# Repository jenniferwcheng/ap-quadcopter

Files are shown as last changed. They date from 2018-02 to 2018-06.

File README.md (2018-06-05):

# IEEE@UCLA Advanced 2017-2018
Quadcopter

## Process:
* Select Pro Mini in Aruduino IDE
* Compile + Upload
* If it doesn't work, try pressing/holding the reset button on the board between compile and upload

## Layout of Motors:
```
RB = Red/Blue
BW = Black/White
RB BW
BW RB
```

## TO-DO:
* Figure out ports and #define them all
* Crimp motor wires and attach them via female JST to board
* Get battery and test individual motor (analogWrite to control speed)
* Attach all motors to plastic body
* Try flying while held down with all 4 motors and rotors
* Attach gyroscope/accelerometer
* Do actual error correction + control using sensors
* Attach radio
* Implement radio control

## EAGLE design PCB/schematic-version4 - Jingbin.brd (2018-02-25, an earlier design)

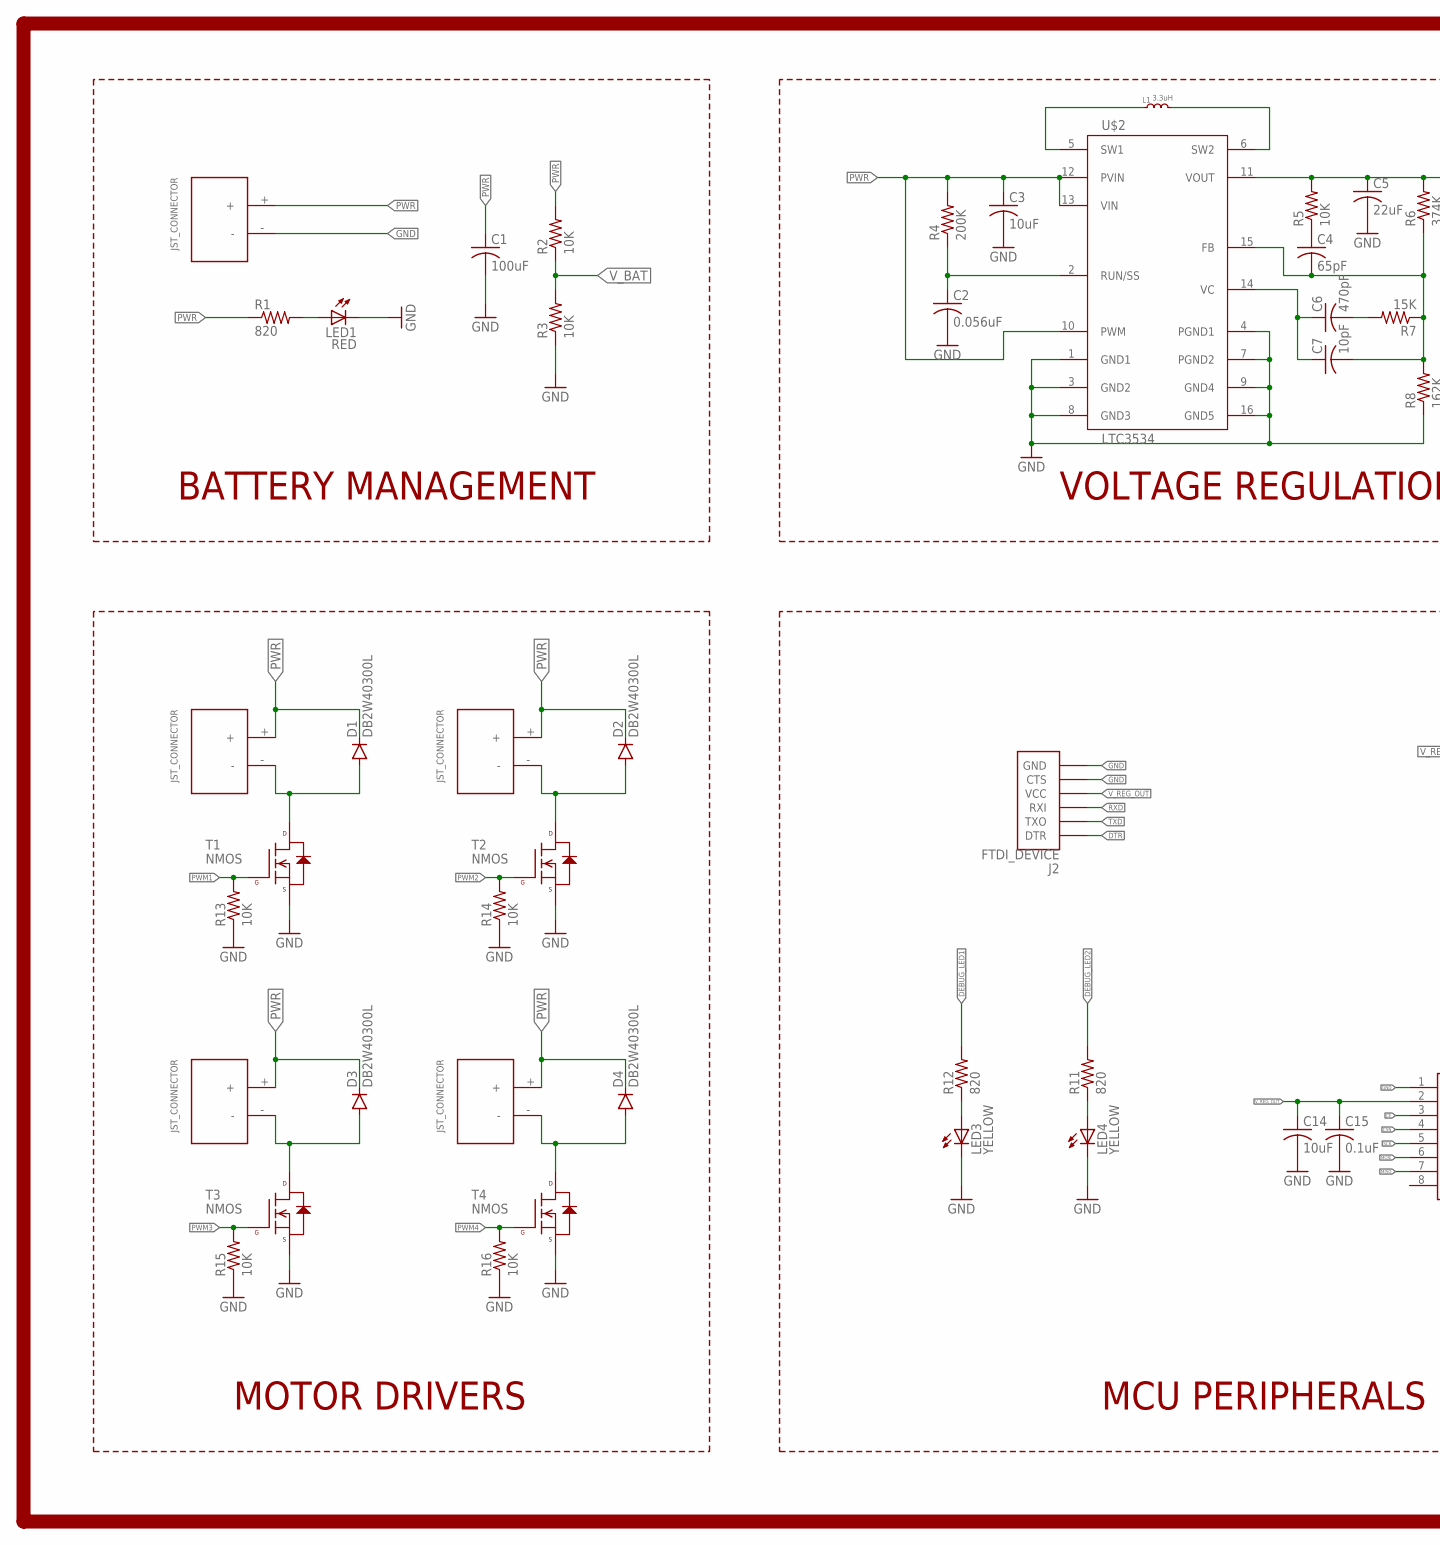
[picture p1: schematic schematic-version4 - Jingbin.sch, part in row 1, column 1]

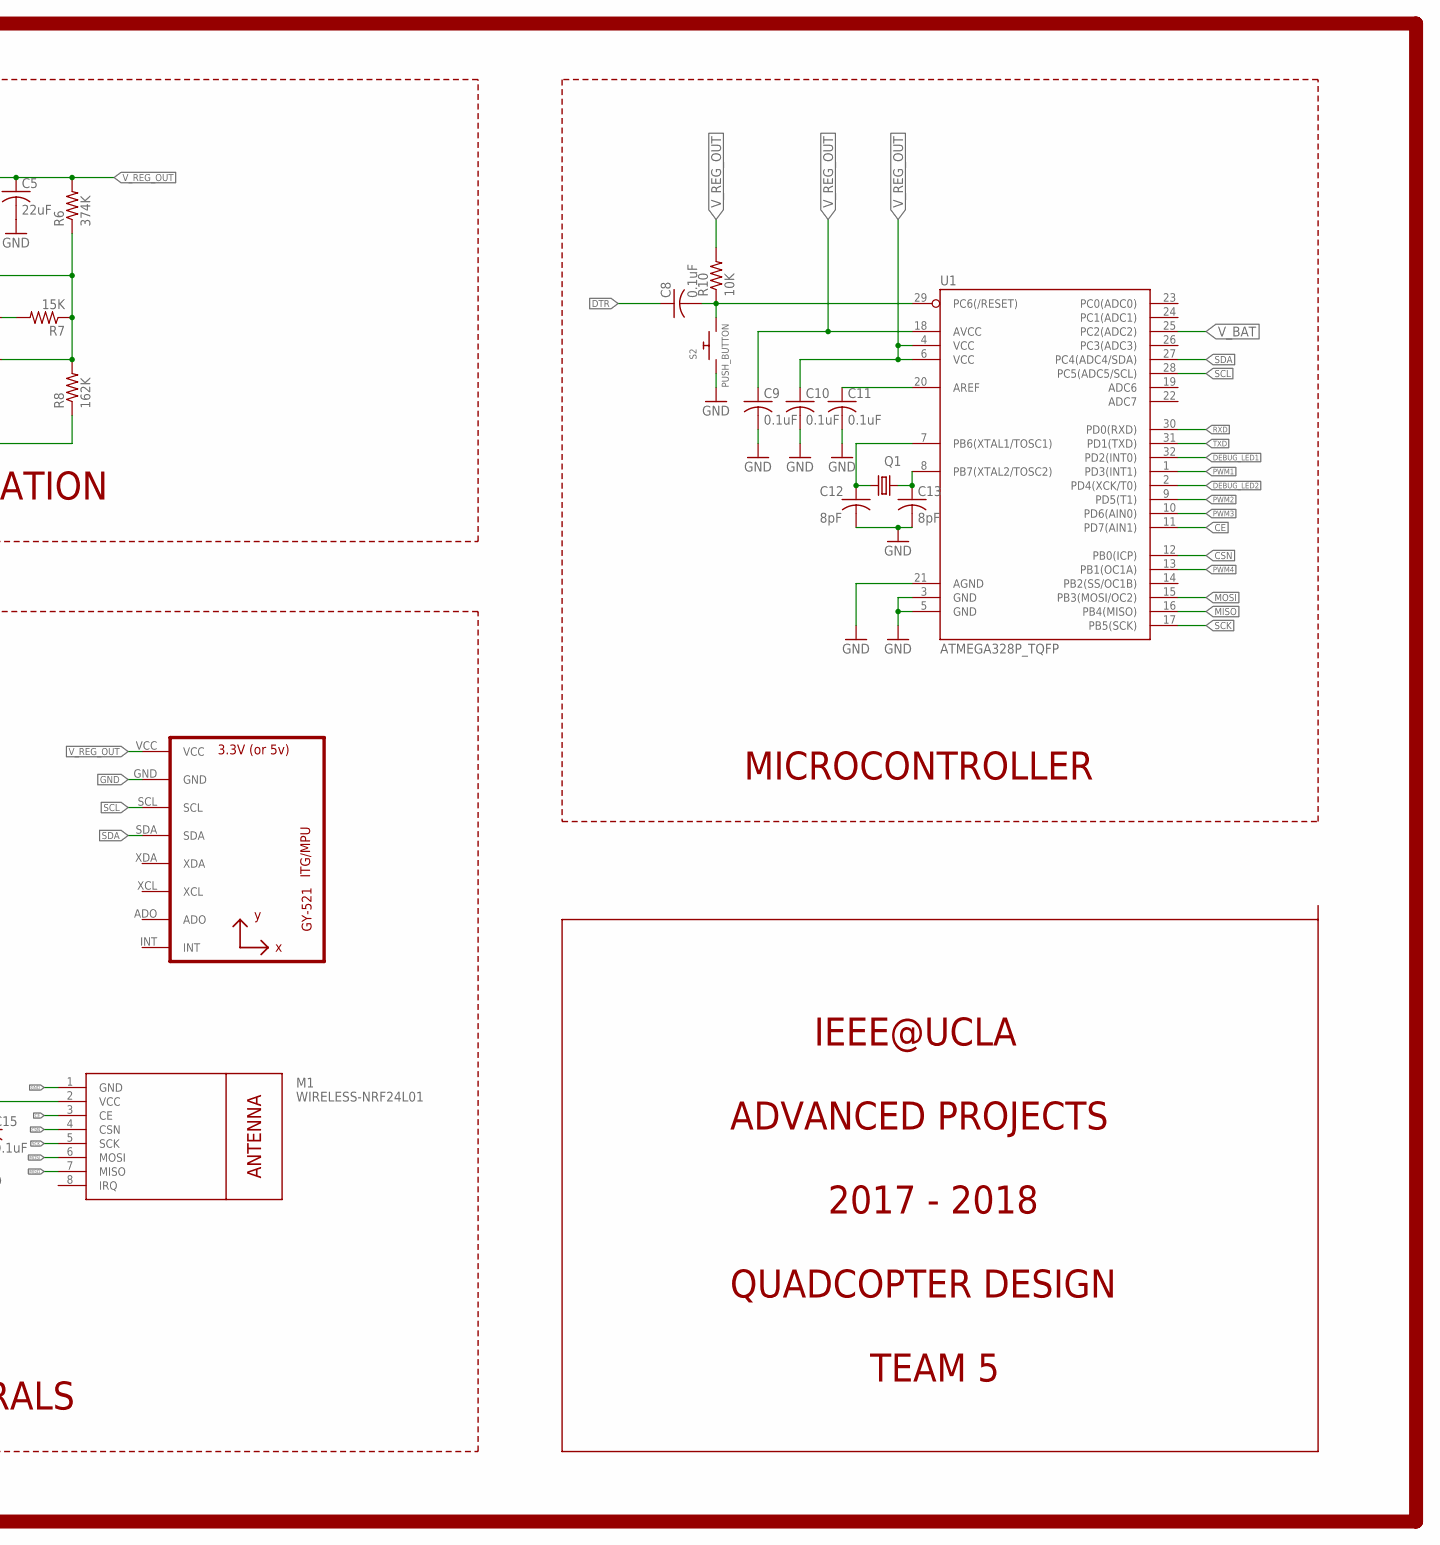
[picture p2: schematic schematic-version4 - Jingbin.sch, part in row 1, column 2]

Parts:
C1: 100uF; C1206
C2: 0.056uF; C0603
C3, C14: 10uF; C0603
C4: 65pF; C1206
C5: 22uF; C0603
C6: 470pF; C0603
C7: 10pF; C0603
C8, C9, C10, C11, C15: 0.1uF; C0603
C12, C13: 8pF; C0603
D1, D2, D3, D4: DB2W40300L; MINI2-F3-B
J2: FTDI_DEVICE; FTDI_DEVICE_SIDE
L1: 3.3uH; XAL4020
LED1: RED; SML0603
LED3, LED4: YELLOW; SML0603
M1: WIRELESS-NRF24L01
Q1: NX3225GD; NX3225GD-CRA-3
R1, R11, R12: 820; R0603
R2, R3, R5, R10, R13, R14, R15, R16: 10K; R0603
R4: 200K; R0603
R6: 374K; R0603
R7: 15K; R0603
R8: 162K; R0603
S2: PUSH_BUTTON; PUSHBUTTON_SMD_SJ
T1, T2, T3, T4: NMOS; SOT23-3
U1: ATMEGA328P_TQFP; TQFP32-08
U2: GY-521MPU6050; GY-521
U$1, U$4, U$7, U$10, U$13: JST_CONNECTOR_FEMALE
U$2: LTC3534; SSOP-16GN

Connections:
CE: M1.3 (CE), U1.11 (PD7(AIN1))
CSN: M1.4 (CSN), U1.12 (PB0(ICP))
DEBUG_LED1: R12.2, U1.32 (PD2(INT0))
DEBUG_LED2: R11.2, U1.2 (PD4(XCK/T0))
DTR: C8.1, J2.P$1 (DTR)
GND: C1.2, C2.2, C3.2, C5.2, C9.2, C10.2, C11.2, C12.2, C13.2, C14.2, C15.2, J2.P$5 (CTS), J2.P$6 (GND), LED1.C, LED3.C, LED4.C, M1.1 (GND), R3.1, R8.1, R13.1, R14.1, R15.1, R16.1, S2.P$1, T1.2 (S), T2.2 (S), T3.2 (S), T4.2 (S), U1.3 (GND), U1.5 (GND), U1.21 (AGND), U2.GND, U$1.-, U$2.1 (GND1), U$2.3 (GND2), U$2.4 (PGND1), U$2.7 (PGND2), U$2.8 (GND3), U$2.9 (GND4), U$2.16 (GND5)
MISO: M1.7 (MISO), U1.16 (PB4(MISO))
MOSI: M1.6 (MOSI), U1.15 (PB3(MOSI/OC2))
unnamed: C12.1, Q1.P$1 (1), U1.7 (PB6(XTAL1/TOSC1))
unnamed: C8.2, R10.1, S2.P$2, U1.29 (PC6(/RESET))
unnamed: D1.POS (PPIN), T1.3 (D), U$4.-
unnamed: C13.1, Q1.P$2 (2), U1.8 (PB7(XTAL2/TOSC2))
unnamed: D2.POS (PPIN), T2.3 (D), U$7.-
unnamed: D3.POS (PPIN), T3.3 (D), U$10.-
unnamed: D4.POS (PPIN), T4.3 (D), U$13.-
unnamed: L1.1, U$2.5 (SW1)
unnamed: L1.2, U$2.6 (SW2)
unnamed: LED1.A, R1.2
unnamed: LED3.A, R12.1
unnamed: LED4.A, R11.1
unnamed: C4.1, R5.1
unnamed: C2.1, R4.1, U$2.2 (RUN/SS)
unnamed: C4.2, C7.2, R6.1, R7.1, R8.2, U$2.15 (FB)
unnamed: C6.1, C7.1, U$2.14 (VC)
unnamed: C6.2, R7.2
unnamed: C11.1, U1.20 (AREF)
PWM1: R13.2, T1.1 (G), U1.1 (PD3(INT1))
PWM2: R14.2, T2.1 (G), U1.9 (PD5(T1))
PWM3: R15.2, T3.1 (G), U1.10 (PD6(AIN0))
PWM4: R16.2, T4.1 (G), U1.13 (PB1(OC1A))
PWR: C1.1, C3.1, D1.NEG (GPIN), D2.NEG (GPIN), D3.NEG (GPIN), D4.NEG (GPIN), R1.1, R2.2, R4.2, U$1.+, U$2.10 (PWM), U$2.12 (PVIN), U$2.13 (VIN), U$4.+, U$7.+, U$10.+, U$13.+
RXD: J2.P$3 (RXI), U1.30 (PD0(RXD))
SCK: M1.5 (SCK), U1.17 (PB5(SCK))
SCL: U1.28 (PC5(ADC5/SCL)), U2.SCL
SDA: U1.27 (PC4(ADC4/SDA)), U2.SDA
TXD: J2.P$2 (TXO), U1.31 (PD1(TXD))
V_BAT: R2.1, R3.2, U1.25 (PC2(ADC2))
V_REG_OUT: C5.1, C9.1, C10.1, C14.1, C15.1, J2.P$4 (VCC), M1.2 (VCC), R5.2, R6.2, R10.2, U1.4 (VCC), U1.6 (VCC), U1.18 (AVCC), U2.VCC, U$2.11 (VOUT)

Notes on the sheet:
BATTERY MANAGEMENT
VOLTAGE REGULATION
MOTOR DRIVERS
MCU PERIPHERALS
MICROCONTROLLER
IEEE@UCLA
ADVANCED PROJECTS
2017 - 2018
QUADCOPTER DESIGN
TEAM 5

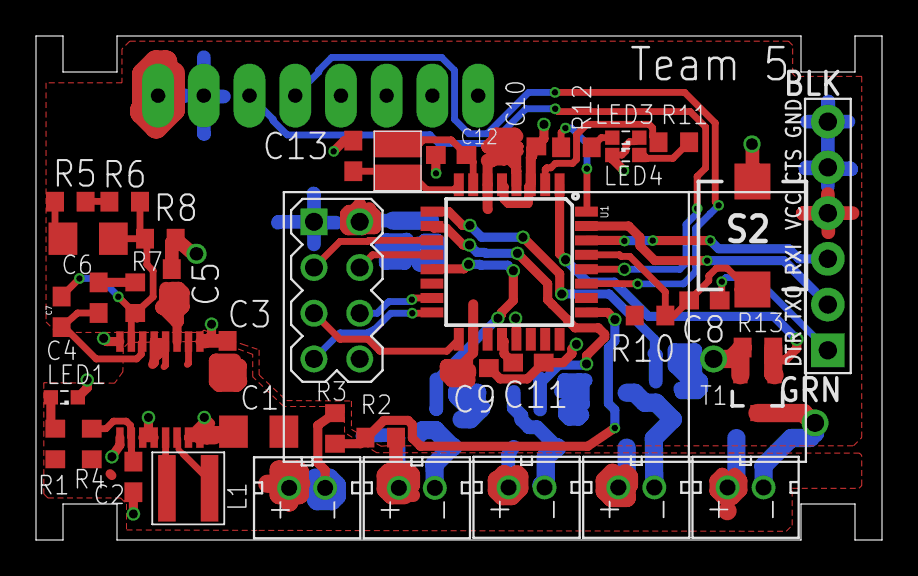
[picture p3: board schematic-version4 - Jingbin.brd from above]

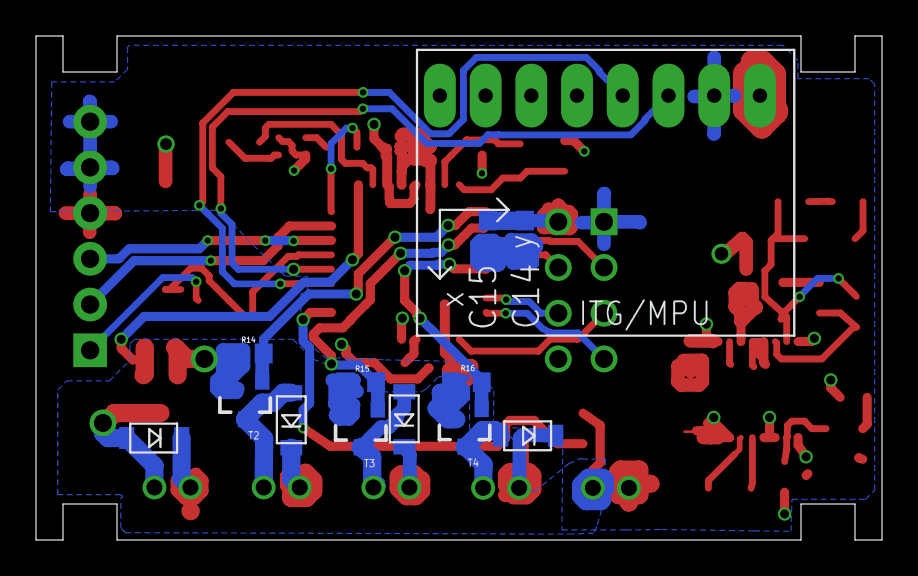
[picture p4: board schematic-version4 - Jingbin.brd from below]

Board: 2 copper layers, 47.0 x 28.0 mm, 54 parts (13 on the bottom side), 38 nets.

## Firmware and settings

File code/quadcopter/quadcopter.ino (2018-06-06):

#define PWM1 3
#define PWM2 5
#define PWM3 6
#define PWM4 9

#define debug1 2
#define debug2 4

#define SCL A5
#define SDA A4

#define CE 7
#define CSN 8
#define MOSI 11
#define MISO 12

void setup() {
  //setup_gyro();
  pinMode(PWM1,OUTPUT);
  pinMode(PWM2,OUTPUT);
  pinMode(PWM3,OUTPUT);
  pinMode(PWM4,OUTPUT);
  pinMode(debug1,OUTPUT);
  pinMode(debug2,OUTPUT);
}

void loop() {
  //loop_gyro();
  digitalWrite(debug1,HIGH);
  digitalWrite(debug2,HIGH);

  analogWrite(PWM4,10);
  analogWrite(PWM3,10);
  analogWrite(PWM2,10);
  analogWrite(PWM1,10);
  delay(1000);

  digitalWrite(debug1,LOW);
  digitalWrite(debug2,LOW);

  delay(100);
}

// sensor fusion stuff
#include "sensor_fusion.h"
// DEFINE INT_STATUS IN HEADER

struct vector bias_a, bias_g, orient, orient_c;
int max_Samples = 75;
unsigned long timel = 0;
unsigned long prev_time = 0;

struct data{
  int x,y,z;
} acc, gyro;

void setup_gyro() {
  //configure device
  //set PWR_MGMT_1 register to take the IMU out of sleep mode
  uint8_t pwr_mgmt_1;
  readReg(0x6B, &pwr_mgmt_1, 1);
  pwr_mgmt_1 = 0xBF & pwr_mgmt_1; //disable SLEEP
  writeReg(0x6B, &pwr_mgmt_1, 1);
  //set GYRO_CONFIG register to the largest possible full-scale range to enable the
  //detection of high-velocity rotations
  uint8_t gyro_config;
  readReg(0x1B, &gyro_config, 1);
  gyro_config = 0x18 | gyro_config; //highest thingy
  writeReg(0x1B, &gyro_config, 1);
  //set CONFIG register to the largest possible bandwidth
  uint8_t configy;
  readReg(0x1A, &configy, 1);
  configy = 0xF8 & configy;
  writeReg(0x1A, &configy, 1);
  //enable DATA_RDY
//  uint8_t RDY;
//  readReg(0x38, &RDY, 1);
//  RDY = RDY | 0x01;
//  writeReg(0x38, &RDY, 1);

  Serial.begin(115200);
  //uint8_t *WHOAMI;
  //readReg(0x75,WHOAMI,1);
  //Serial.println(String(*WHOAMI));

  bias_a.x = bias_a.y = bias_a.z = 0;
  bias_g.x = bias_g.y = bias_g.z = 0;

  // Get samples
  for (int i = 1; i <= max_Samples; i++) {

    if (getData()) {

      bias_a.x += ((float)acc.x)/16384 - 0;
      bias_a.y += ((float)acc.y)/16384 - 0;
      bias_a.z += ((float)acc.z)/16384 - 1;

      bias_g.x += ((float)gyro.x)/16.384 - 0;
      bias_g.y += ((float)gyro.y)/16.384 - 0;
      bias_g.z += ((float)gyro.z)/16.384 - 0;

      //Serial.println("Loop" + String(i));
      //printVector(bias_a);
      //printVector(bias_g);
      //printVector(acc,"acc");
      //printVector(gyro,"gyro");
    }
    else {
      //Serial.println("No data");
      i--;
    }
  }

  bias_a.x /= max_Samples;
  bias_a.y /= max_Samples;
  bias_a.z /= max_Samples;

  bias_g.x /= max_Samples;
  bias_g.y /= max_Samples;
  bias_g.z /= max_Samples;

//  printVector(bias_a);
//  printVector(bias_g);
  //init orient to up
  orient.x = orient.y = 0;
  orient.z = 1;

  orient_c.x = orient_c.y = 0;
  orient_c.z = 1;
}



void loop_gyro() {
  if (getData()) {
    //find unit acceleration vector
    struct vector a=scaleReading(acc,"acc");
    vector unit_a;
    vector_normalize(&a, &unit_a);
    printVector(unit_a);

    //rotate quaternion to show orientation
    struct vector g = scaleReading(gyro,"gyro");
    vector unit_g;
    float len = vector_normalize(&g, &unit_g);
    struct quaternion q;
    timel = micros();
    //Serial.print(" ");
    //Serial.println(len,4);

    //deal with init case
    if(prev_time == 0) len = 0;

    float timebt = (timel-prev_time)/1000000.0;
//    Serial.println(timebt,4);
    quaternion_create(&unit_g, -len*timebt, &q);
    prev_time = timel;

    vector result;
    quaternion_rotate(&orient, &q, &result);
    orient = result;
    Serial.print(" ");
    printVector(orient);

    //complementary filter

    //apply low/high pass filter

    //add and normalize
    vector comp,sum,p1,p2,r;
    
    quaternion_rotate(&orient_c, &q, &r);
    float alpha = 0.5;
    vector_multiply(&unit_a, alpha, &p1);
    vector_multiply(&r, 1.0-alpha, &p2);
    vector_add(&p1, &p2, &sum);
    vector_normalize(&sum, &comp);

    Serial.print(" ");
    printVector(comp);
    Serial.println();

    orient_c = comp;
  }

  
  delay(10);
}

void printVector(struct vector v) {
  Serial.print(v.x);
  Serial.print(" ");
  Serial.print(v.y);
  Serial.print(" ");
  Serial.print(v.z);
  //Serial.println();
}

struct vector scaleReading(struct data a, String s){
  struct vector v;
  if(s=="acc"){
    v.x=((float)a.x)/16384-bias_a.x;
    v.y=((float)a.y)/16384-bias_a.y;
    v.z=((float)a.z)/16384-bias_a.z;
  }
  else {
    v.x=((float)a.x)/16.384-bias_g.x;
    v.y=((float)a.y)/16.384-bias_g.y;
    v.z=((float)a.z)/16.384-bias_g.z;
    v.x *= 0.017453;
    v.y *= 0.017453;
    v.z *= 0.017453;
  }
  return v;
}

//convert to g's and print
void printVector(struct data v, String s) {
  if (s=="acc"){
    Serial.print((((float)v.x)/16384),4);
    Serial.print(" ");
    Serial.print((((float)v.y)/16384),4);
    Serial.print(" ");
    Serial.print((((float)v.z)/16384),4);
    Serial.println();
  }
  else {
    Serial.print((((float)v.x)/16.4),4);
    Serial.print(" ");
    Serial.print((((float)v.y)/16.4),4);
    Serial.print(" ");
    Serial.print((((float)v.z)/16.4),4);
    Serial.println();
  }
}

/* Get data about x y z coordinates from accelerometer and gyroscope.
   Takes in two structs, acc and gyro. If data is available, acc and gyro
   will be filled with the x y z coordinates and the function returns true.
   Otherwise it returns false and structs are not touched.*/
bool getData() {
  uint8_t buf,buf2;
  readReg(0x3A, &buf, 1);
  //Serial.println(String(buf));
  if ((buf)&0x01) {
    //read acc
    readReg(0x3B, &buf, 1);
    readReg(0x3C, &buf2, 1);
    acc.x = (buf<<8) | buf2;
    readReg(0x3D, &buf, 1);
    readReg(0x3E, &buf2, 1);
    acc.y = (buf<<8) | buf2;
    readReg(0x3F, &buf, 1);
    readReg(0x40, &buf2, 1);
    acc.z = (buf<<8) | buf2;

    //read gyro
    readReg(0x43, &buf, 1);
    readReg(0x44, &buf2, 1);
    gyro.x = (buf<<8) | buf2;
    readReg(0x45, &buf, 1);
    readReg(0x46, &buf2, 1);
    gyro.y = (buf<<8) | buf2;
    readReg(0x47, &buf, 1);
    readReg(0x48, &buf2, 1);
    gyro.z = (buf<<8) | buf2;

    return true;
  }
  return false;
}

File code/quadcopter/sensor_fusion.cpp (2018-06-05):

#include <Arduino.h>
#include <Wire.h>
#include "sensor_fusion.h"

void readReg(uint8_t reg, uint8_t *buf, size_t len)
{
    // TODO: Implement
	//page 36
	Wire.beginTransmission(0x68); //start condition?
	Wire.write(reg); 
	Wire.endTransmission(false); 
	
	//restarts
	//Wire.endTransmission(false);
	Wire.requestFrom(0x68,len); //request the reg
	for (int i = 0; i < len; i++) {
		//while(!Wire.available()){}
		buf[i] = Wire.read();
	}
	Wire.endTransmission();
	
}

void writeReg(uint8_t reg, uint8_t *buf, size_t len)
{
    // TODO: Implement
	//page 35
	
	Wire.beginTransmission(byte(0x68)); // send AD+W = 0x68 + W bit (0)
	Wire.write(reg); // send RA
	Wire.write(buf,len); // send DATA
	Wire.endTransmission(true); //send stop signal
}

float vector_normalize(struct vector *raw, struct vector *unit)
{
  float mag = sqrt(pow(raw->x, 2) + pow(raw->y, 2) + pow(raw->z, 2));
  if(mag != 0) {
      unit->x = raw->x / mag;
      unit->y = raw->y / mag;
      unit->z = raw->z / mag;
  }
  return mag;
}

void vector_add(struct vector *v1, struct vector *v2, struct vector *result)
{
  result->x = v1->x + v2->x;
  result->y = v1->y + v2->y;
  result->z = v1->z + v2->z;
}

void vector_multiply(struct vector *v, float c, struct vector *result)
{
  result->x = v->x * c;
  result->y = v->y * c;
  result->z = v->z * c;
}

void quaternion_create(struct vector *v, float angle, struct quaternion *result)
{
  result->r = cos(angle/2);
  result->i = v->x * sin(angle/2);
  result->j = v->y * sin(angle/2);
  result->k = v->z * sin(angle/2);
}

void quaternion_rotate(struct vector *v, struct quaternion *q, struct vector *result)
{
  struct vector n;
  memcpy(&n, v, sizeof(n));
  result->x = n.x * (1 - 2*(pow(q->j, 2) + pow(q->k, 2))) + n.y * 2*(q->i * q->j - q->k * q->r) + n.z * 2*(q->i * q->k + q->j * q->r);
  result->y = n.x * 2*(q->i * q->j + q->k * q->r) + n.y * (1 - 2*(pow(q->i, 2) + pow(q->k, 2))) + n.z * 2*(q->j * q->k - q->i * q->r);
  result->z = n.x * 2*(q->i * q->k - q->j * q->r) + n.y * 2*(q->j * q->k + q->i * q->r) + n.z * (1 - 2*(pow(q->i, 2) + pow(q->j, 2)));
}

void quaternion_multiply(struct quaternion *q1, struct quaternion *q2, struct quaternion *result)
{
  result->r = q1->r * q2->r - q1->i * q2->i - q1->j * q2->j - q1->k * q2->k;
  result->i = q1->r * q2->i + q1->i * q2->r + q1->j * q2->k - q1->k * q2->j;
  result->j = q1->r * q2->j - q1->i * q2->k + q1->j * q2->r + q1->k * q2->i;
  result->k = q1->r * q2->k + q1->i * q2->j - q1->j * q2->i + q1->k * q2->r;
}

float vector_roll(struct vector *v)
{
  return atan2(v->x, sqrt(pow(v->z, 2) + pow(v->y, 2)));
}

float vector_pitch(struct vector *v)
{
  return -atan2(v->y, v->z);
}

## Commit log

2018-01-24 Added sensor, RF
    Need work on voltage regulator, header for FDTI, more decoupling,
    [schematic.sch]
2018-01-25 Added (mostly compelte) v-reg circuit
    [schematic.sch]
2018-01-25 completed v_reg external, decouplng, labels
    Need work on adding control switches, indicator LEDs. Need to find all correct parts and replace current placeholder symbols
    [schematic.sch]
2018-01-26 Added LEDs, switches, motor circuit, and made it look pretty
    Still need to get all the correct parts to replace place-holder
    [schematic.sch]
2018-01-26 added pull-down for motor
    [schematic.sch]
2018-01-26 Fixed all warnings, added more debug LEDs
    [schematic.sch]
2018-01-27 Added load capacitor for crystal
    [schematic.sch]
2018-01-28 Updated parts to reflect actual selection
    [schematic.brd, schematic.sch]
2018-01-28 Changed voltage divider values
    [schematic.brd, schematic.sch]
2018-01-28 added slide switch
    [schematic.brd, schematic.sch]
2018-01-28 Included libraries for some parts
    Adafruit for push button.
    Coilcraft for inductor used in voltage regulator.
    Wurth for sliding switch
2018-01-30 Removed switch, changed some names, removed an unnecessary capacitor
    Changed power from battery to PWR instead of VCC, to be exact
    [schematic.brd]
2018-01-31 Fixed issues mentioned in design review
    Changed voltage divider resistors to 10K.
    Got new voltage regulator, completely circuit and PCD footprint.
    Changed all component package to 0603.
    [schematic.brd, schematic.sch]
2018-02-01 Fixed issues from schematic pre-check
    Changed package of R15,R16 to 0603.
    CHange 100pF capacitor to 68pF to be closer to recommended value.
    [schematic.brd, schematic.sch]
2018-02-02 65pF capacitor 1206 package
    [schematic.brd, schematic.sch]
2018-02-02 fixed programmer RX TX
    [schematic.brd, schematic.sch]
2018-02-03 Fixed LED package
    [schematic.brd, schematic.sch]
2018-02-07 started PCB design
2018-02-07 Started PCB design
    Current plan: motor driver on bottom, RF module on bottom, need to space out top to make room for reset push button and debug LED
    [schematic.brd]
2018-02-08 Restarting design
    [schematic - Copy.brd, schematic - Copy.sch]
2018-02-08 PCB First Draft done
    No errors
    [schematic-PCBdone.brd, schematic-PCBdone.sch]
2018-02-09 changed pwm routes to 20 width and fixed clearance
    should do polygons for gnd and power
2018-02-10 Made some changes according to review notes
    Fixed FTDI connector, added keepout outline to voltage regulator. Changes are reflected in version2 file. version2 board is empty for you routing pleasure.
    [schematic-version2.brd, schematic-version2.sch]
2018-02-13 Added anohter finished version
    Need to fix clearence issues
    [schematic-version2 - Jigbin.brd, schematic-version2 - Jigbin.sch, schematic-version2.brd]
2018-02-13 Fixed problems in my version 2
    [schematic-version2 - Jigbin.brd]
2018-02-13 Changed V_BAT trace from thin to thic
    [schematic-version2 - Jigbin.brd]
2018-02-14 Another draft
    Radio on top, IMU on bottom. Ground plane on bottom. Left half of top plane is PWR, for motor needs. Right half of top plane is regulated output, for MCU, radio, and IMU needs.
    [schematic-version3 - Jigbin.brd, schematic-version3 - Jigbin.sch]
2018-02-15 Yet another attempt
    Pretty much no bottleneck, but have components under IMU, need fix
    [schematic-version4 - Jingbin.brd, schematic-version4 - Jingbin.sch]
2018-02-15 Version 4 complete
    [schematic-version4 - Jingbin.brd]
2018-02-15 More adjustments to widen some paths and ensure multiple connection
    [schematic-version4 - Jingbin.brd]
2018-02-15 added archive folder
    [schematic-PCBdone.brd, schematic-PCBdone.sch, schematic-version2 - Jigbin.brd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]
2018-02-16 Added new crystal
    [schematic-version4 - Jingbin.brd, schematic-version4 - Jingbin.sch]
2018-02-16 More adjustments to version4, version5 is empty
    [schematic-version5 - Jingbin.brd, schematic-version5 - Jingbin.sch]
2018-02-20 More space for VREGOUT near voltage regulator
    [schematic-version4 - Jingbin.brd]
2018-02-20 Fixed DRC error in previous commit
    [schematic-version4 - Jingbin.brd]
2018-02-20 More paths, hopefully less bottleneck
    [schematic-version4 - Jingbin.brd]
2018-02-20 Slightly adjusted trace thickness
    [schematic-version4 - Jingbin.brd]
2018-02-20 Moved radio decoupling capacitor closer to radio power
    [schematic-version4 - Jingbin.brd]
2018-02-20 More finer adjustments
    [schematic-version4 - Jingbin.brd]
2018-02-20 I swear it's the last time
    [schematic-version4 - Jingbin.brd]
2018-02-20 More paths...
    [schematic-version4 - Jingbin.brd]
2018-02-21 More thicc paths
    [schematic-version4 - Jingbin.brd]
2018-02-21 Added silkscreen
    [schematic-version4 - Jingbin.brd]
2018-02-21 Removed thermal for motor 4
    [schematic-version4 - Jingbin.brd]
2018-02-25 Change 100uF capacitor size
    [schematic-version4 - Jingbin.brd, schematic-version4 - Jingbin.sch]
2018-05-31 lit up LED3
2018-06-05 Defined ports in INO file
    [schematic-version4 - Jingbin.brd, schematic-version4 - Jingbin.sch, schematic-version5 - Jingbin.brd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]
2018-06-05 test motor
2018-06-05 added sensor fusion code

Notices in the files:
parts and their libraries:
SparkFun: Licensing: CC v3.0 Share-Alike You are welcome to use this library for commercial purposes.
